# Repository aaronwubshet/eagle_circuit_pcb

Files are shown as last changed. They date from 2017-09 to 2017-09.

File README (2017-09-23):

####################################################
#############NODE ELECTRONICS#######################
####################################################
DESCRIPTION:

NODE IS A MISSION TO SEND A NANOSAT INTO LOW EARTH ORIBIT. THESE FILES ARE PART OF THE LASER COMMUNICATION SYSTEM SELF TEST FEATURE. 
GOAL OF THE CIRUITRY IS TO ENSURE THE LASER POWER LEVEL IS NOT TOO HIGH NOR TOO LOW AT DIFFERENT POINTS OR MODULATION BEFORE 
BEING USED IN ACTUAL COMMUNICATIONS

FILES CATEGORIES:

(1) DATA SHEETS
(2) SCHEMATIC PDF
(3) EAGLE SCHEMATIC FILES
(4) EAGLE LIBRARY FILE
(5) *COMING SOON* EAGLE BOARD FILE

OVERVIEW OF CONTENTS:

LIGHT DIODE AMPLIFIER CIRCUITRY AND RELEVANT DATA SHEETS

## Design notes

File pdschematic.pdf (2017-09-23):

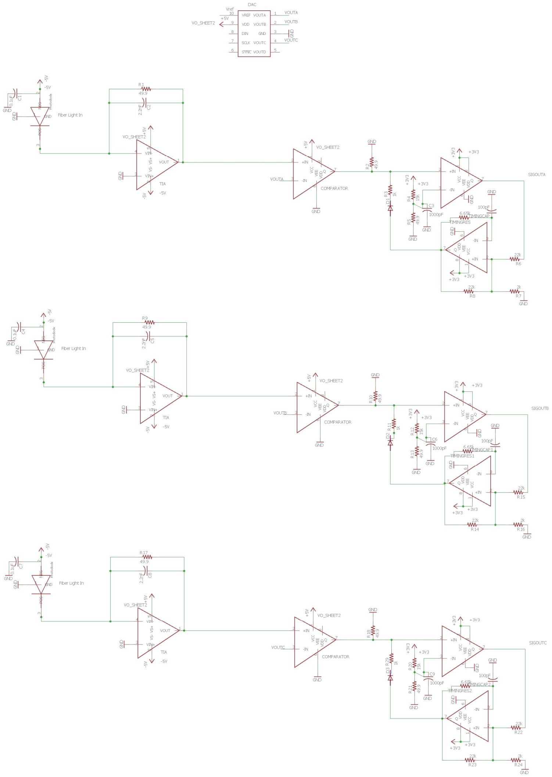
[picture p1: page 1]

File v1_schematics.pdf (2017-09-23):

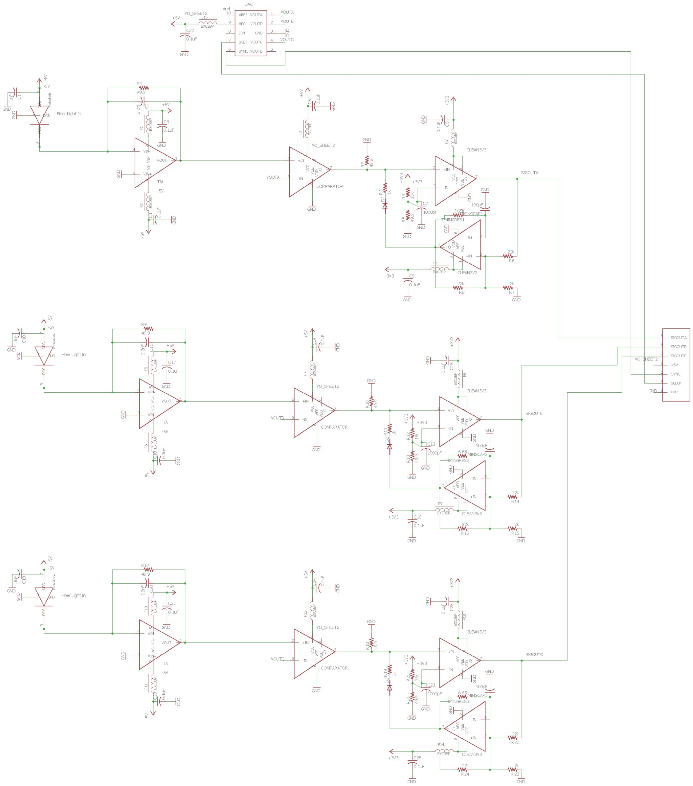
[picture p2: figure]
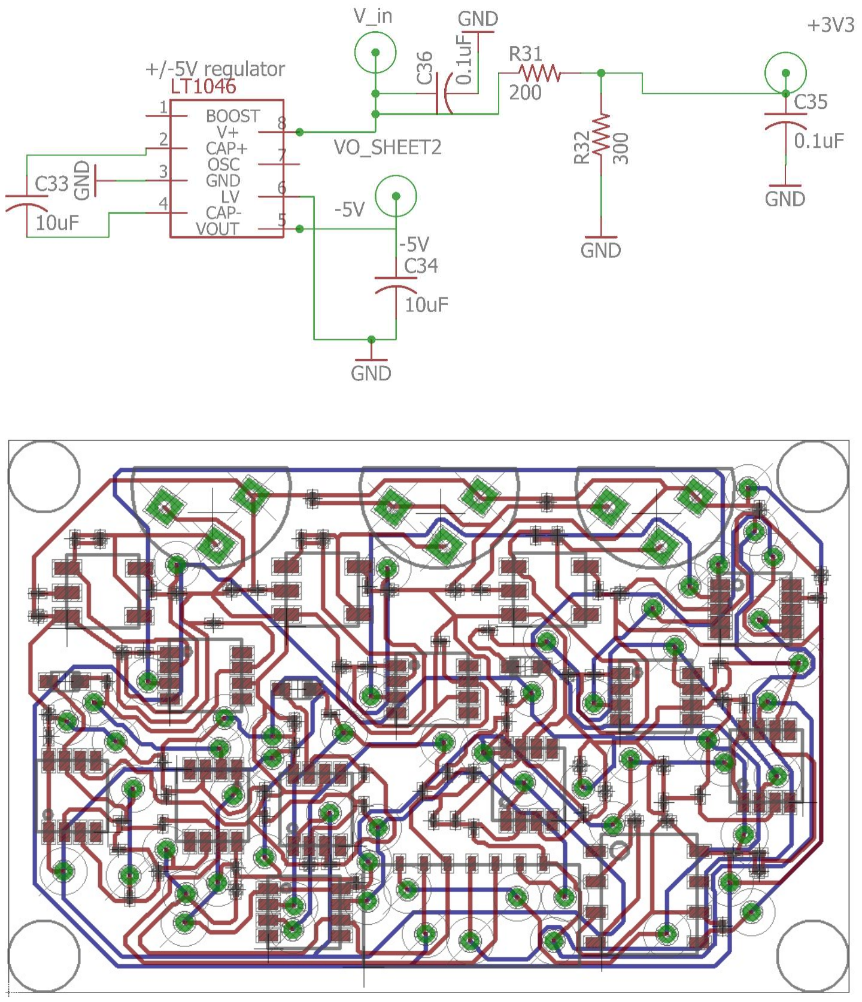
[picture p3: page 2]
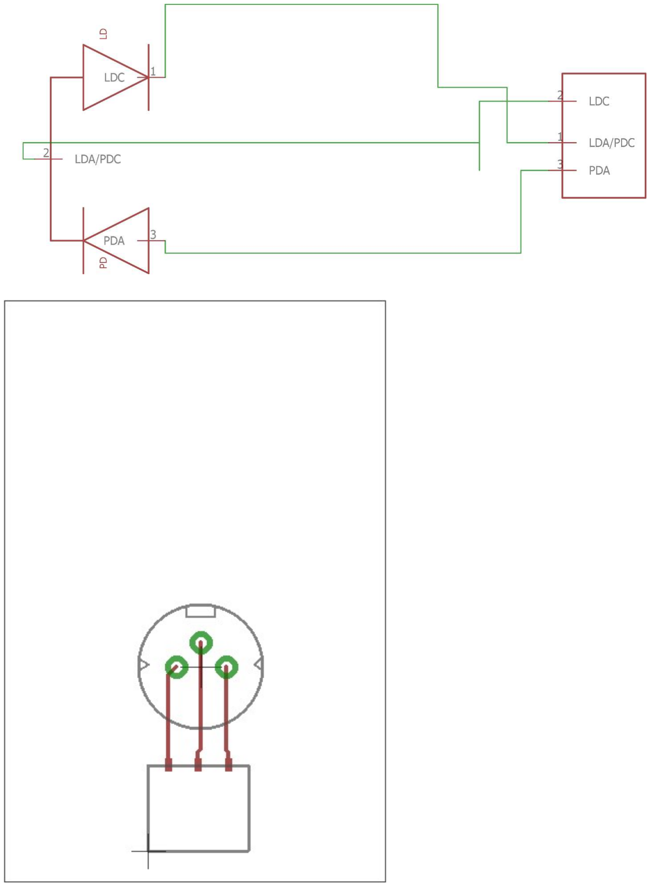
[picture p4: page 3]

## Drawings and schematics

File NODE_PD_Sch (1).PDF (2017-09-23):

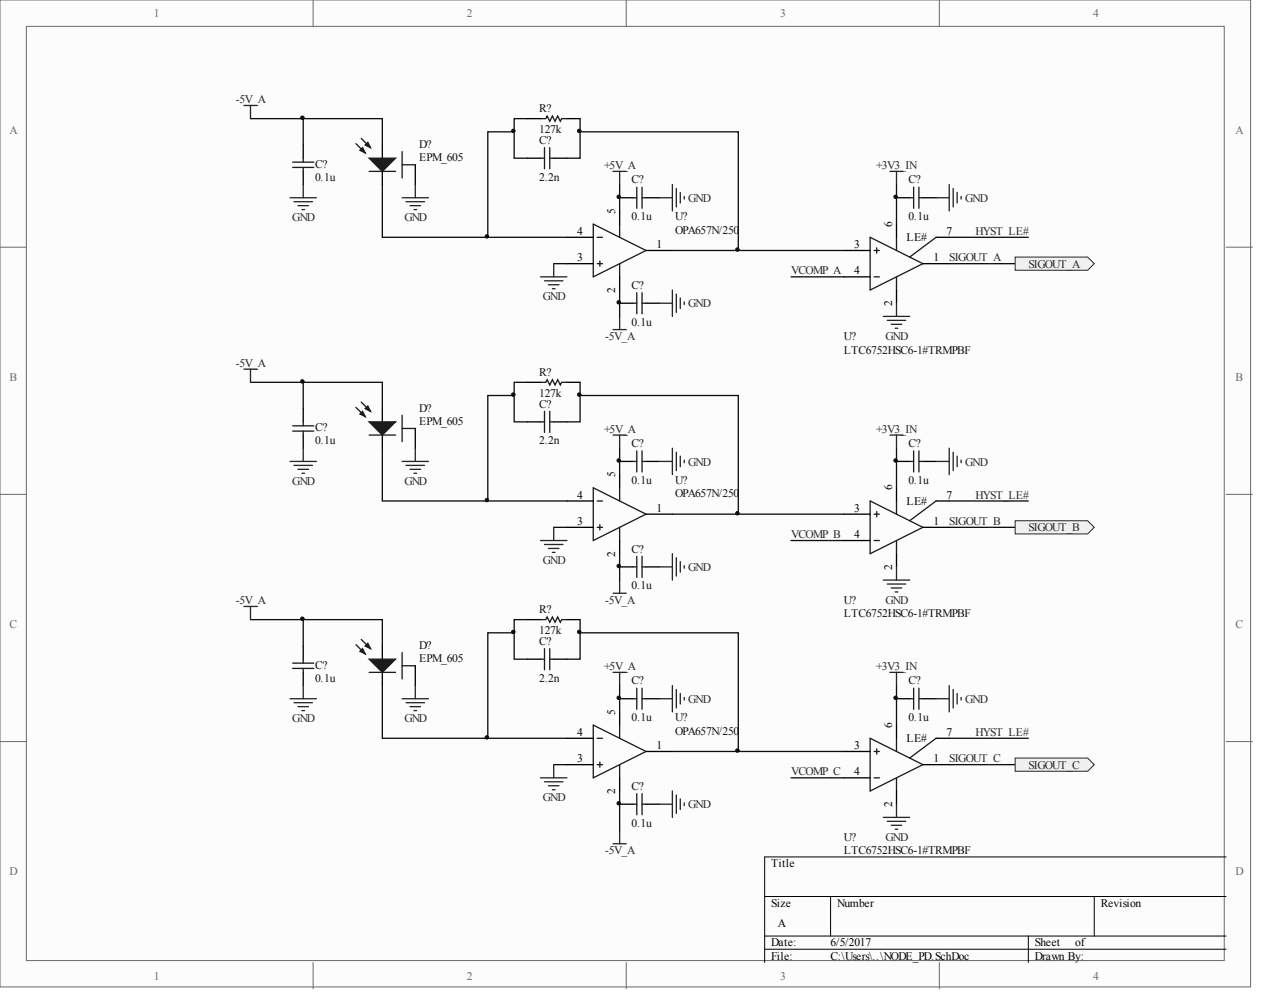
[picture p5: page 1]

Size A | Number | Revision

Date: 6/5/2017 | Sheet of
File: C:\Users\..\NODE_PD.SchDoc | Drawn By:

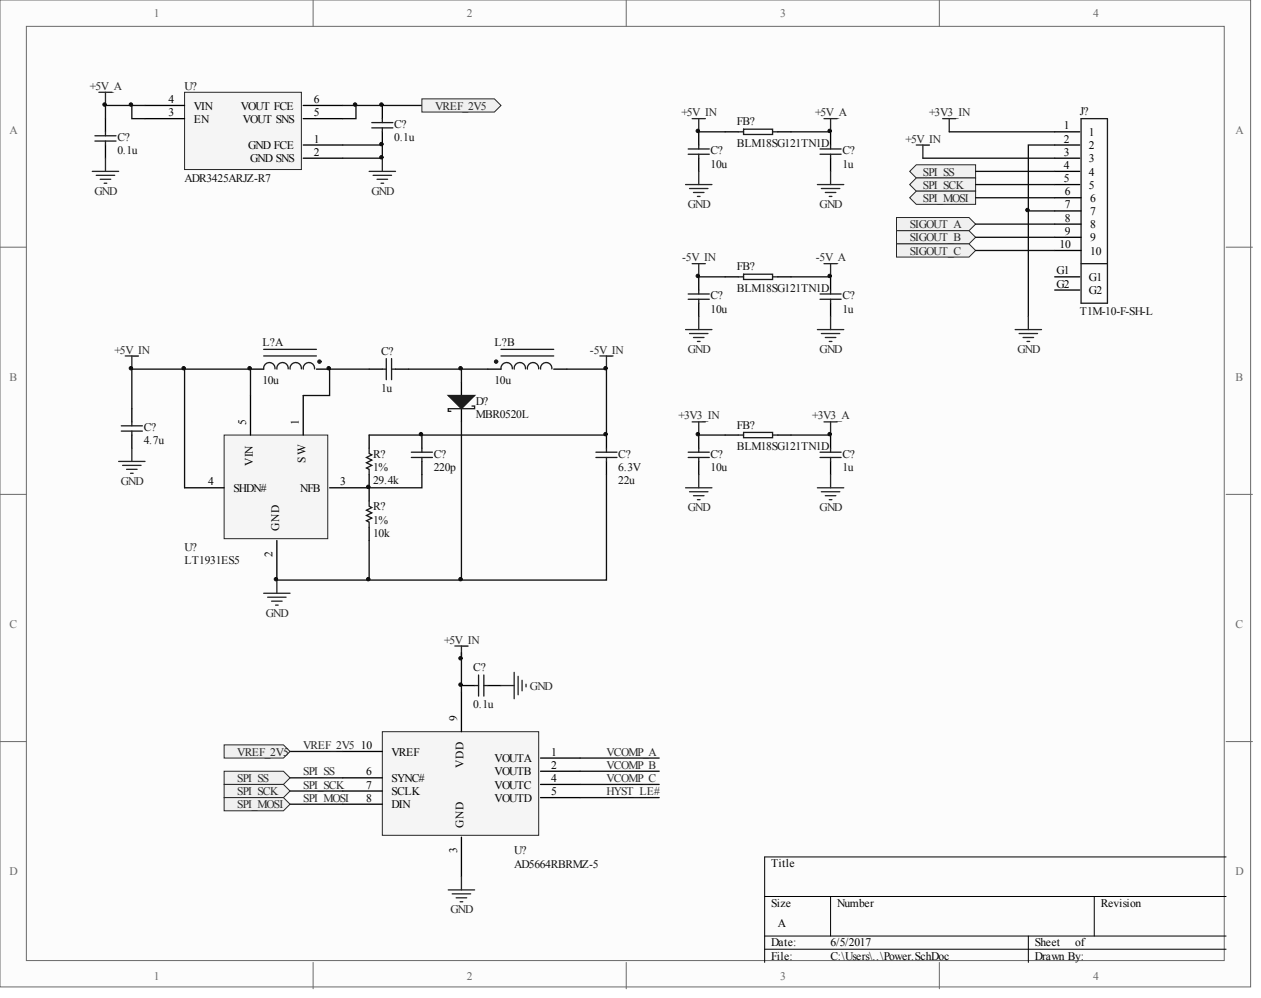
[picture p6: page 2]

NFB | R? 3 SHDN# 4

Size A | Number | Revision

Date: 6/5/2017 | Sheet of
File: C:\Users\..\Power.SchDoc | Drawn By:

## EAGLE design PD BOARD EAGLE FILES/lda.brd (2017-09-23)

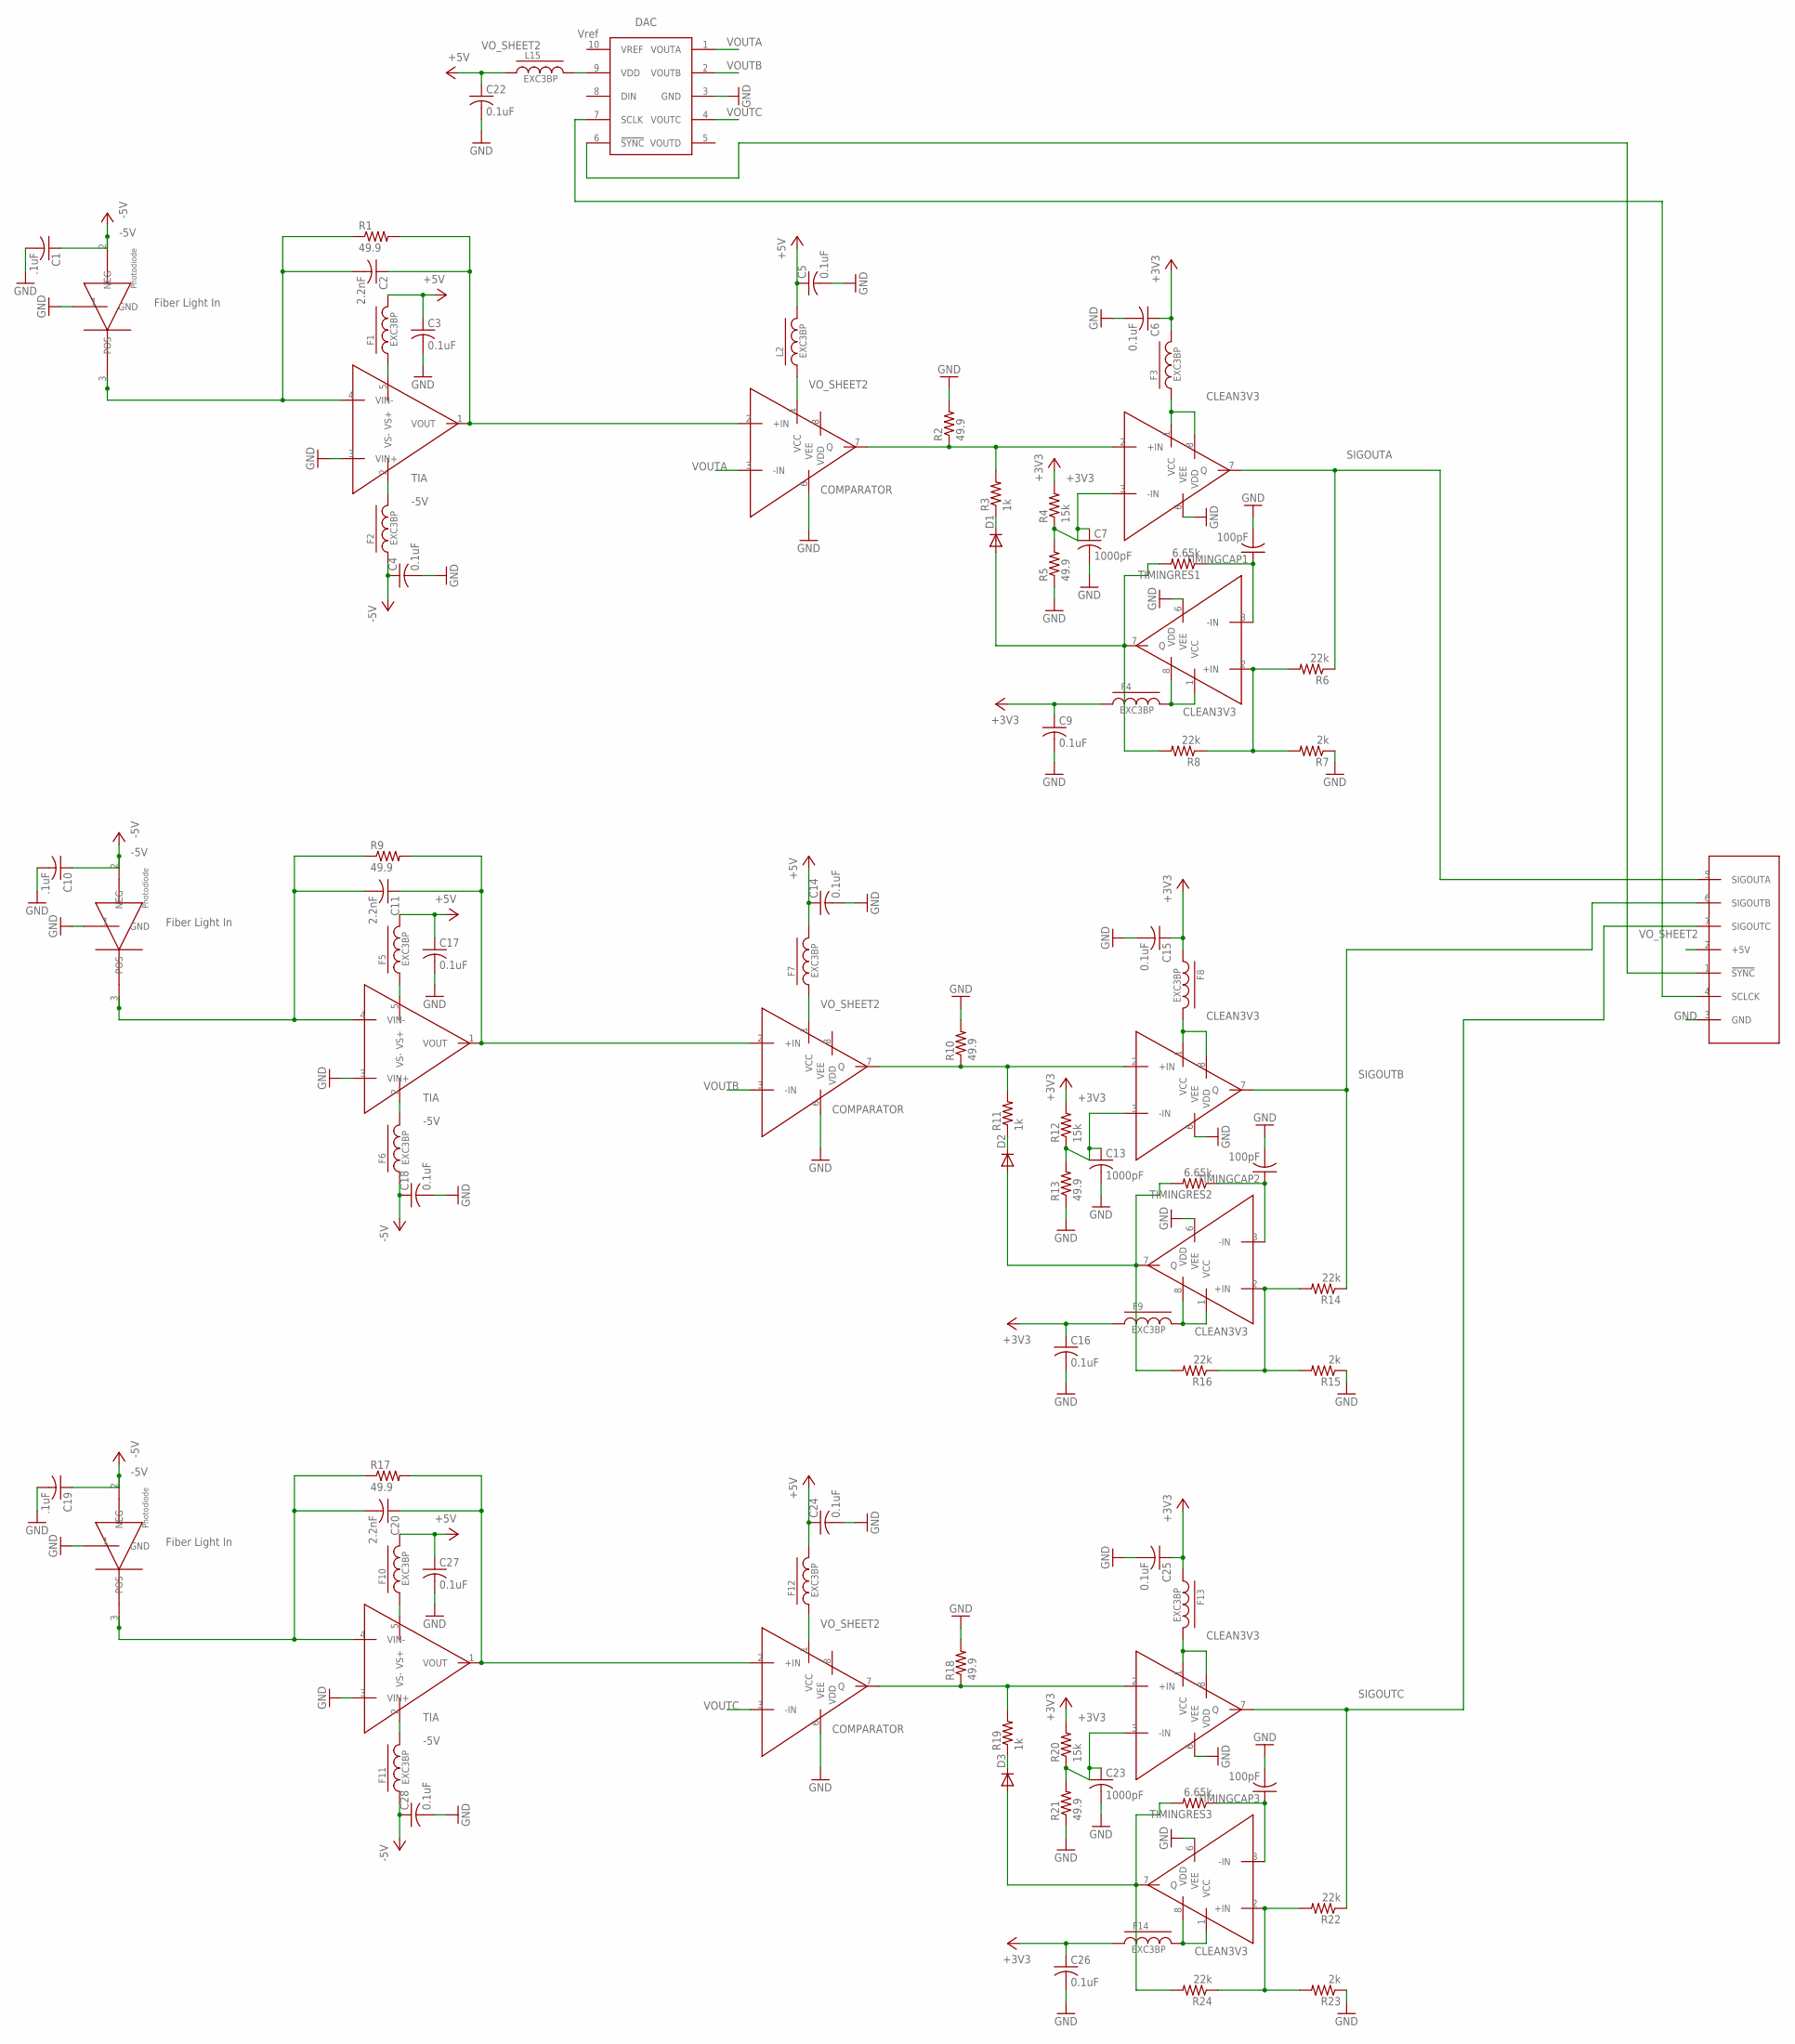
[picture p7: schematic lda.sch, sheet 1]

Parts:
C1, C10, C19: .1uF; C01005
C2, C11, C20: 2.2nF; C01005
C3, C4, C5, C6, C9, C14, C15, C16, C17, C18, C22, C24, C25, C26, C27, C28: 0.1uF; C01005
C7, C13, C23: 1000pF; C01005
COMPARATOR1, COMPARATOR2, COMPARATOR3, COMPARATOR4, COMPARATOR5, COMPARATOR6, COMPARATOR7, COMPARATOR8, COMPARATOR9: LTC6752DEV; MS8-MSOP
D1, D2, D3: DIODE-SOD523; SOD523
DAC: AD5624DEV; AD5624MSOP
F1, F2, F3, F4, F5, F6, F7, F8, F9, F10, F11, F12, F13, F14: EXC3BP; R01005
L2, L15: EXC3BP; R01005
PD1, PD2, PD3: EPM605DEV; PINPDBOX
R1, R2, R5, R9, R10, R13, R17, R18, R21: 49.9; R01005
R3, R11, R19: 1k; R01005
R4, R12, R20: 15k; R01005
R6, R8, R14, R16, R22, R24: 22k; R01005
R7, R15, R23: 2k; R01005
TIA1, TIA2, TIA3: OPA657DEV; OPA-SOIC
TIMINGCAP1, TIMINGCAP2, TIMINGCAP3: 100pF; C01005
TIMINGRES1, TIMINGRES2, TIMINGRES3: 6.65k; R01005
U$2: SAMTEC7PIN

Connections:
+3V3: C6.1, C9.1, C15.1, C16.1, C25.1, C26.1, F3.2, F4.1, F8.1, F9.1, F13.1, F14.1, R4.2, R12.2, R20.2; also elsewhere on the board
-5V: C1.1, C4.1, C10.1, C18.1, C19.1, C28.1, F2.1, F6.1, F11.1, PD1.2 (NEG), PD2.2 (NEG), PD3.2 (NEG); also elsewhere on the board
CLEAN3V3: COMPARATOR2.1 (VCC), COMPARATOR2.8 (VDD), COMPARATOR3.1 (VCC), COMPARATOR3.8 (VDD), COMPARATOR5.1 (VCC), COMPARATOR5.8 (VDD), COMPARATOR6.1 (VCC), COMPARATOR6.8 (VDD), COMPARATOR8.1 (VCC), COMPARATOR8.8 (VDD), COMPARATOR9.1 (VCC), COMPARATOR9.8 (VDD), F3.1, F4.2, F8.2, F9.2, F13.2, F14.2
GND: C1.2, C3.2, C4.2, C5.2, C6.2, C7.2, C9.2, C10.2, C13.2, C14.2, C15.2, C16.2, C17.2, C18.2, C19.2, C22.2, C23.2, C24.2, C25.2, C26.2, C27.2, C28.2, COMPARATOR1.6 (VEE), COMPARATOR2.6 (VEE), COMPARATOR3.6 (VEE), COMPARATOR4.6 (VEE), COMPARATOR5.6 (VEE), COMPARATOR6.6 (VEE), COMPARATOR7.6 (VEE), COMPARATOR8.6 (VEE), COMPARATOR9.6 (VEE), DAC.3 (GND), PD1.1 (GND), PD2.1 (GND), PD3.1 (GND), R2.2, R5.1, R7.1, R10.2, R13.1, R15.1, R18.2, R21.1, R23.1, TIA1.3 (VIN+), TIA2.3 (VIN+), TIA3.3 (VIN+), TIMINGCAP1.2, TIMINGCAP2.2, TIMINGCAP3.2, U$2.3 (GND); also elsewhere on the board
unnamed: F1.1, TIA1.5 (VS+)
unnamed: F2.2, TIA1.2 (VS-)
unnamed: COMPARATOR1.1 (VCC), L2.1
unnamed: C2.1, COMPARATOR1.2 (+IN), R1.2, TIA1.1 (VOUT)
unnamed: DAC.6 (!SYNC), U$2.1 (!SYNC)
unnamed: COMPARATOR1.7 (Q), COMPARATOR2.2 (+IN), R2.1, R3.2
unnamed: D1.C, R3.1
unnamed: COMPARATOR3.7 (Q), D1.A, R8.2, TIMINGRES1.2
unnamed: DAC.9 (VDD), L15.2
unnamed: COMPARATOR3.3 (-IN), TIMINGCAP1.1, TIMINGRES1.1
unnamed: C7.1, COMPARATOR2.3 (-IN), R4.1, R5.2
unnamed: COMPARATOR3.2 (+IN), R6.2, R7.2, R8.1
unnamed: C11.1, COMPARATOR4.2 (+IN), R9.2, TIA2.1 (VOUT)
unnamed: COMPARATOR4.7 (Q), COMPARATOR6.2 (+IN), R10.1, R11.2
unnamed: D2.C, R11.1
unnamed: COMPARATOR5.7 (Q), D2.A, R16.2, TIMINGRES2.2
unnamed: COMPARATOR5.3 (-IN), TIMINGCAP2.1, TIMINGRES2.1
unnamed: C13.1, COMPARATOR6.3 (-IN), R12.1, R13.2
unnamed: COMPARATOR5.2 (+IN), R14.2, R15.2, R16.1
unnamed: C11.2, PD2.3 (POS), R9.1, TIA2.4 (VIN-)
unnamed: F5.1, TIA2.5 (VS+)
unnamed: F6.2, TIA2.2 (VS-)
unnamed: COMPARATOR4.1 (VCC), F7.1
unnamed: C20.1, COMPARATOR7.2 (+IN), R17.2, TIA3.1 (VOUT)
unnamed: C2.2, PD1.3 (POS), R1.1, TIA1.4 (VIN-)
unnamed: COMPARATOR7.7 (Q), COMPARATOR9.2 (+IN), R18.1, R19.2
unnamed: D3.C, R19.1
unnamed: COMPARATOR8.7 (Q), D3.A, R24.2, TIMINGRES3.2
unnamed: COMPARATOR8.3 (-IN), TIMINGCAP3.1, TIMINGRES3.1
unnamed: C23.1, COMPARATOR9.3 (-IN), R20.1, R21.2
unnamed: COMPARATOR8.2 (+IN), R22.2, R23.2, R24.1
unnamed: C20.2, PD3.3 (POS), R17.1, TIA3.4 (VIN-)
unnamed: F10.1, TIA3.5 (VS+)
unnamed: F11.2, TIA3.2 (VS-)
unnamed: COMPARATOR7.1 (VCC), F12.1
unnamed: DAC.7 (SCLK), U$2.4 (SCLCK)
SIGOUTA: COMPARATOR2.7 (Q), R6.1, U$2.5 (SIGOUTA)
SIGOUTB: COMPARATOR6.7 (Q), R14.1, U$2.6 (SIGOUTB)
SIGOUTC: COMPARATOR9.7 (Q), R22.1, U$2.7 (SIGOUTC)
VOUTA: COMPARATOR1.3 (-IN), DAC.1 (VOUTA)
VOUTB: COMPARATOR4.3 (-IN), DAC.2 (VOUTB)
VOUTC: COMPARATOR7.3 (-IN), DAC.4 (VOUTC)
VO_SHEET2: C3.1, C5.1, C14.1, C17.1, C22.1, C24.1, C27.1, F1.2, F5.2, F7.2, F10.2, F12.2, L2.2, L15.1, U$2.2 (+5V); also elsewhere on the board

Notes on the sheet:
DAC
Vref
Fiber Light In
TIA
COMPARATOR

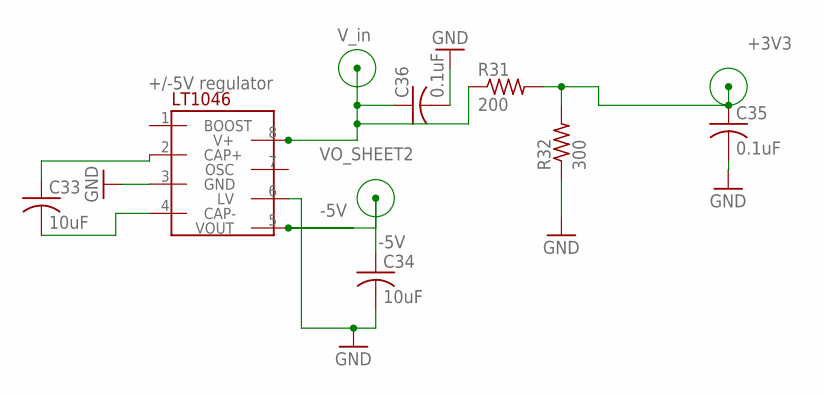
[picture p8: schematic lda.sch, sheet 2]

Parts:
C33, C34: 10uF; C01005
C35, C36: 0.1uF; C01005
R31: 200; R01005
R32: 300; R01005
U$1: LT1046REG; S8

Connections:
+3V3: C35.1, R31.2, R32.2; also elsewhere on the board
-5V: C34.1, U$1.5 (VOUT); also elsewhere on the board
GND: C34.2, C35.2, C36.2, R32.1, U$1.3 (GND), U$1.6 (LV); also elsewhere on the board
unnamed: C33.2, U$1.4 (CAP-)
unnamed: C33.1, U$1.2 (CAP+)
VO_SHEET2: C36.1, R31.1, U$1.8 (V+); also elsewhere on the board

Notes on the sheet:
+/-5V regulator
-5V
V_in

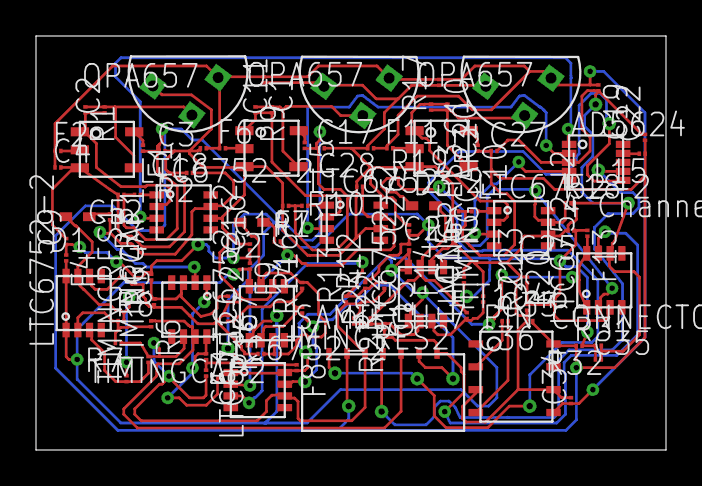
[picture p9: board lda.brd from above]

Board: 4 copper layers, 35.0 x 23.0 mm, 98 parts (0 on the bottom side), 49 nets.
